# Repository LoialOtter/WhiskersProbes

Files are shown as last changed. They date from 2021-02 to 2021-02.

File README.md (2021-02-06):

# WhiskersProbes
A set of low cost probes for logic analyzers and oscilloscopes.

## Whiskers-DigitalProbe
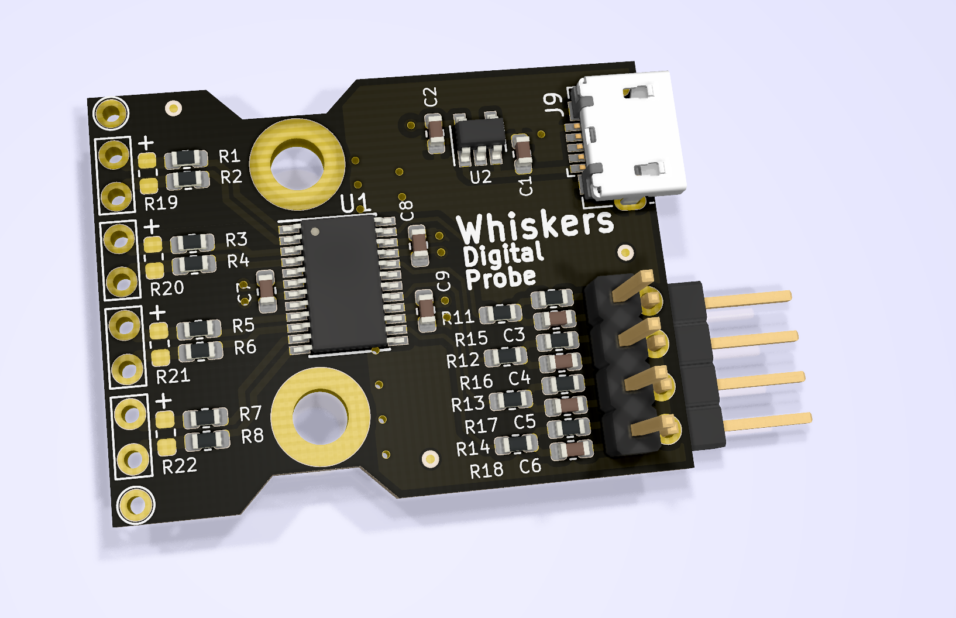
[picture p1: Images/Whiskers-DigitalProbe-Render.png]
Whisker-DigitalProbe


The logic probe is aiming to be a 500MHz+ Differential buffer to single ended for using a logic analyzer on LVDS signals.

Of note, the matching network on the output is to allow you to match the circuit directly to your logic analyzer input. The values shown in the schematic are the ones needed for HP/Agilent/Keysight if you're using ribbon cables. If you're using a logic analyzer input, the capacitors should not be placed and the resistors should be 0 ohm.

## Whiskers-AnalogProbe
Coming soon

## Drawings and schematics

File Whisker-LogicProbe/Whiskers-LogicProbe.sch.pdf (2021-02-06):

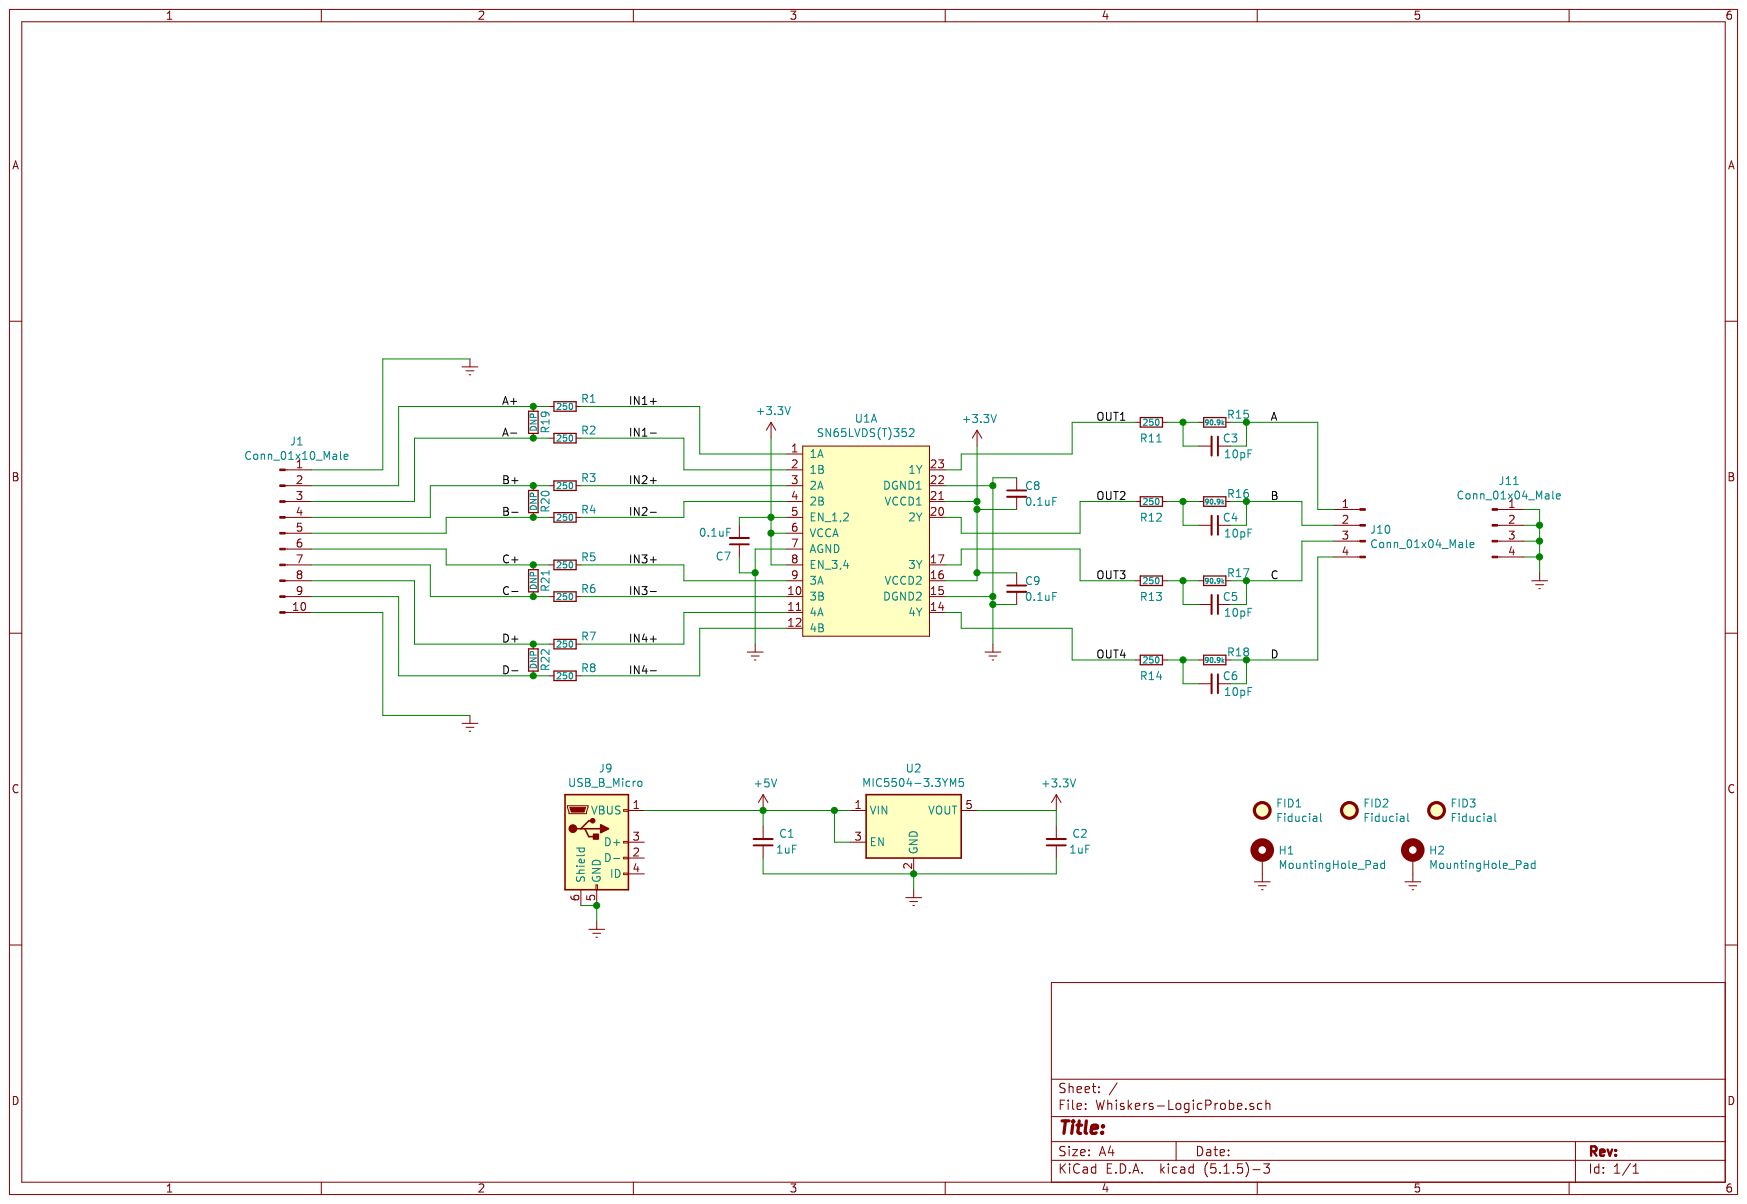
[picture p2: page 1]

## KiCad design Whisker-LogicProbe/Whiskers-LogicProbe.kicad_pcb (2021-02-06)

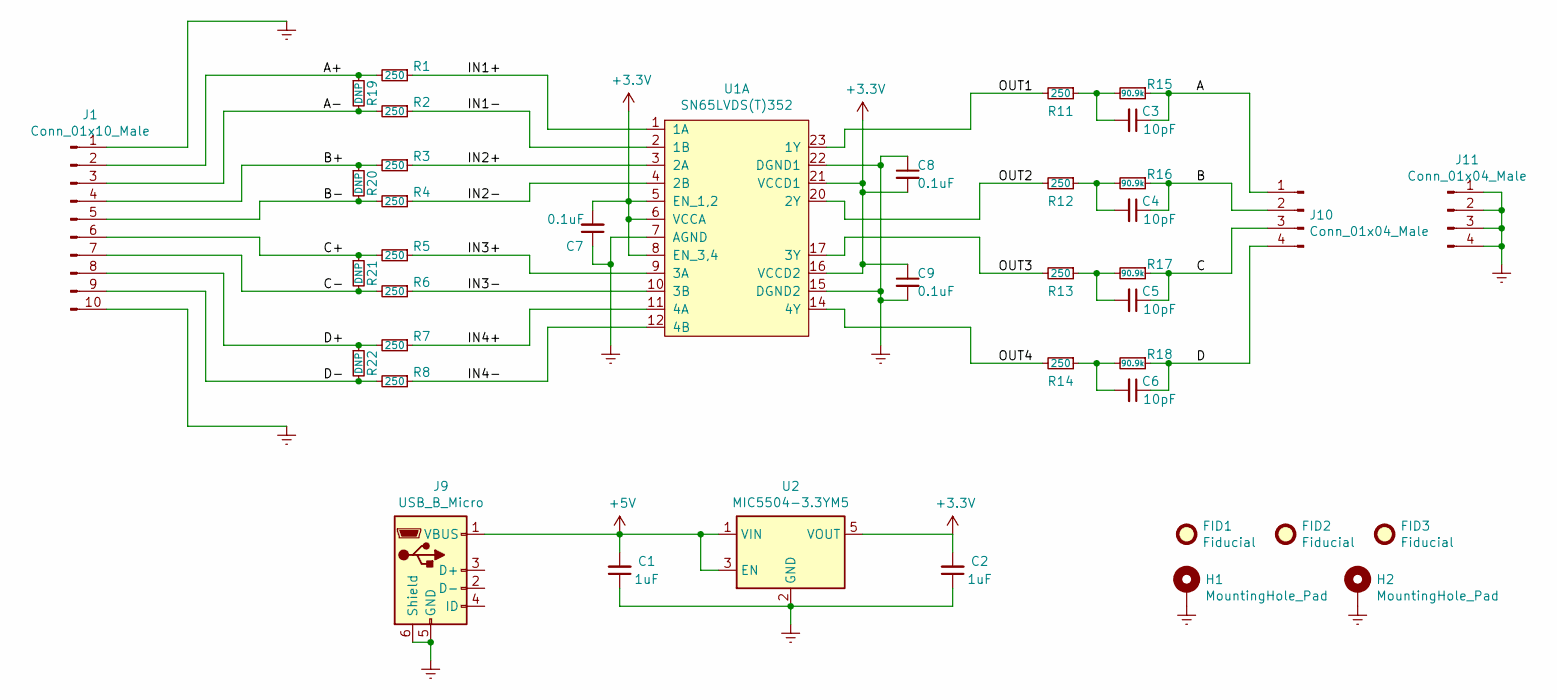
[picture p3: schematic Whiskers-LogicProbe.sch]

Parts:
C1, C2: 1uF; C_0603_1608Metric
C3, C4, C5, C6: 10pF; C_0603_1608Metric
C7, C8, C9: 0.1uF; C_0603_1608Metric
FID1, FID2, FID3: Fiducial; Fiducial_0.5mm_Mask1mm
H1, H2: MountingHole_Pad; MountingHole_3.2mm_M3_DIN965_Pad
J1: Conn_01x10_Male; PinHeader_1x10_P2.54mm_Vertical
J9: USB_B_Micro; USB_Micro-B_GCT_USB3076-30-A
J10: Conn_01x04_Male; PinHeader_1x04_P2.54mm_Vertical
J11: Conn_01x04_Male; PinHeader_1x04_P2.54mm_Horizontal
R1, R2, R3, R4, R5, R6, R7, R8, R11, R12, R13, R14: 250; R_0603_1608Metric
R15, R16, R17, R18: 90.9k; R_0603_1608Metric
R19, R20, R21, R22: DNP; R_0603_1608Metric
U1: SN65LVDS(T)352; TSSOP-24_4.4x7.8mm_P0.65mm; Digikey 296-12649-5-ND
U2: MIC5504-3.3YM5; SOT-23-5

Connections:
+3V3: C2.2, C7.2, C8.2, C9.1, U1.5 (EN_1,2), U1.6 (VCCA), U1.8 (EN_3,4), U1.16 (VCCD2), U1.21 (VCCD1), U2.5 (VOUT)
+5V: C1.2, J9.1 (VBUS), U2.1 (VIN), U2.3 (EN)
/A: C3.1, J10.1, R15.1
/A+: J1.2, R1.2, R19.1
/A-: J1.3, R2.2, R19.2
/B: C4.1, J10.2, R16.1
/B+: J1.4, R3.2, R20.1
/B-: J1.5, R4.2, R20.2
/C: C5.1, J10.3, R17.1
/C+: J1.6, R5.2, R21.1
/C-: J1.7, R6.2, R21.2
/D: C6.1, J10.4, R18.1
/D+: J1.8, R7.2, R22.1
/D-: J1.9, R8.2, R22.2
/IN1+: R1.1, U1.1 (1A)
/IN1-: R2.1, U1.2 (1B)
/IN2+: R3.1, U1.3 (2A)
/IN2-: R4.1, U1.4 (2B)
/IN3+: R5.1, U1.9 (3A)
/IN3-: R6.1, U1.10 (3B)
/IN4+: R7.1, U1.11 (4A)
/IN4-: R8.1, U1.12 (4B)
/OUT1: R11.2, U1.23 (1Y)
/OUT2: R12.2, U1.20 (2Y)
/OUT3: R13.2, U1.17 (3Y)
/OUT4: R14.2, U1.14 (4Y)
GNDREF: C1.1, C2.1, C7.1, C8.1, C9.2, H1.1, H2.1, J1.1, J1.10, J9.5 (GND), J9.6 (Shield), J11.1, J11.2, J11.3, J11.4, U1.7 (AGND), U1.15 (DGND2), U1.22 (DGND1), U2.2 (GND)
unnamed: C3.2, R11.1, R15.2
unnamed: C4.2, R12.1, R16.2
unnamed: C5.2, R13.1, R17.2
unnamed: C6.2, R14.1, R18.2

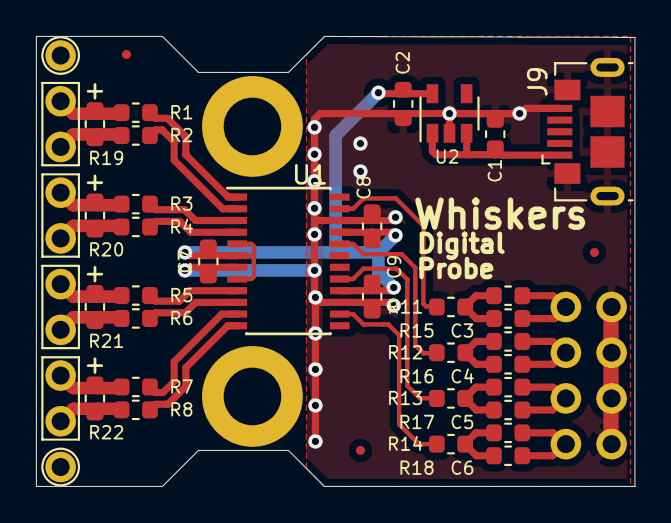
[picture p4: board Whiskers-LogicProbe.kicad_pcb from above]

Board: 2 copper layers, 33.2 x 25.0 mm, 40 parts (1 on the bottom side), 31 nets.

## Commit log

2021-02-06 Initial import of logic probe design
2021-02-06 Import of actual files.
    [Whiskers-LogicProbe.kicad_pcb, Whiskers-LogicProbe.sch]
2021-02-06 Updated to use the proper LVDS receiver chip (560Mb/s one)
    [Whiskers-LogicProbe.kicad_pcb, Whiskers-LogicProbe.sch]
